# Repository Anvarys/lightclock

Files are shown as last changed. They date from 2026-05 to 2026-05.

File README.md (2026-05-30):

<div align="center">
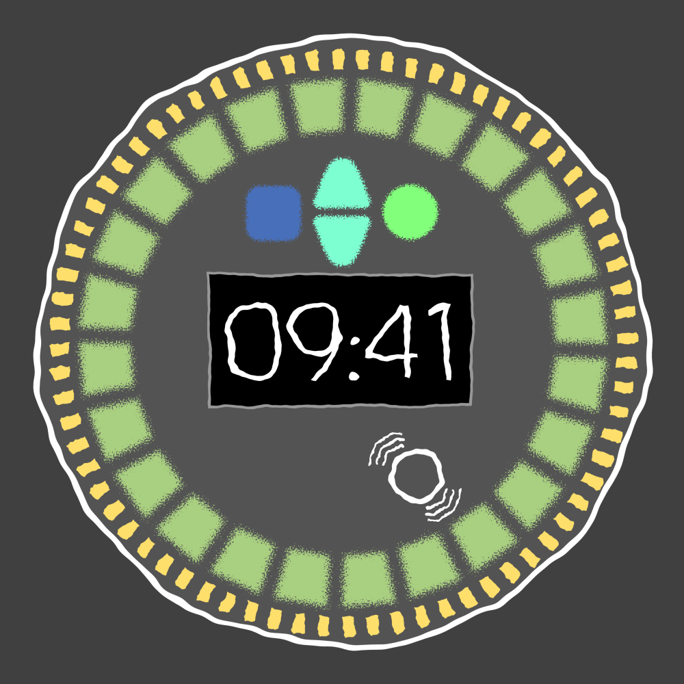
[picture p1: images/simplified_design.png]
Light clock
  
</div>

<h2 align="center">Light Clock</h2>
<p align="center">
A custom PCB-based Clock/Alarm with a runrise alarm, a circle of capacitive touch controls to easily choose the time and a 2.42" OLED display
</p>

## About the project

A custom PCB-based Clock/Alarm with a 3d printed enclosure. It features a runrise alarm option (72 LEDs), a 2.42" OLED display, many capacitive touch controls (24 around in a circle and 4 for the main controls) and a buzzer.

I made this project because I wanted to have a runrise alarm to wake up more naturally and also be easy to set up alarms with few clicks and without any additional installation required.

## Light Clock's features in more detail

### Sunrise alarm & LEDs

Light Clock has a runsrise type of alarm, which will slowly rise the luminosity up to a set time for you to wake up naturally, like with a real sunrise. This can be calibrated, meaning you can set up a test alarm on a day you don't need to wake up at a certain time and see at which luminosity you will wake up. There is also a buzzer (the shaky circle on the simplified design picture) to wake you up with it, just in case, as you might not wake up from the light.

It uses 72LEDs with 3000K warm lighting, with a total maximum luminosity flux of over 2000 lumens. They can also be lighten up in individual groups of 3, so a total of 24 groups is present, to show the current time using those same LEDs but dimmed, also as it has 24 groups it can do both 24 and 12 sections for the time, which you can choose as you prefer.

### Capacitive touch controls

This project has a total of 28 capacitive touch sensors (you can identify all of them on the simplified design picture as the ones having unclear borders), they were made by placing pads on the PCB and using ICs to measure precise capacitance values. 

4 of them are used to control the menu: 2 arrows for navigating between options and change values, a circle to select an option and a square be used as a return button.

And the other 24 are distributed evenly in a circle next to the LEDs, they will be used to easily choose time of your alarm or change number variables. For example if you need to setup an alarm for 10:15am you can simply click the 10th pad counting clockwise from the top to set the hour, and then click on 7th pad to set the minutes.

### Display

The display is a 2.42" OLED display from Waveshare. It has a resolution of 128x64, which is not detailed, but very sufficent for pixeled fonts and interfaces. It will display the time in the format you prefer, and it can be set into a "show on touch" mode, so that the display would be off by default but when you touch any capacitive touch sensor it will show the time for a certain period of time.

### Other

It also has an RTC clock with a coin battery to sustain precise time for months, while the battery is not required it is very recommended as then if you power off the clock you won't need to set up the time again each time.

Since the LEDs and ICs produce heat there is a 40x40x7mm fan on the back which is very quiet, so should not be a worry that it might be disturbing.

Also I added 4 exposed GPIO pads on the PCB that you can use them to integrate something extra to this device if you want to.

## How to build your own light clock

First you would want to buy all the required components found in the [BOM](https://github.com/Anvarys/lightclock/blob/main/BOM/BOM.csv), order the pcb using the gerbers from the [production folder](https://github.com/Anvarys/lightclock/tree/main/PCB/production) (you can also find the positions file which is required for JLCPCB to solder components for you, which is also an option). Then you will need to solder everything by looking at the [schematic](https://github.com/Anvarys/lightclock/blob/main/images/schematic.pdf) for references of the components. Also you will need to 3d print the enclosure, files of which you can find in the [CAD folder](https://github.com/Anvarys/lightclock/tree/main/CAD). Now you will need to flash the device with the [firmware](https://github.com/Anvarys/lightclock/tree/main/firmware) using [VS code](https://code.visualstudio.com) with [PlatformIO](https://platformio.org). Then when you check that it boots up successfully you can assemble the enclosure by first mounting the fan on the back enclosure part, then mounting the pcb to it as well, and finally snap the front enclosure part on the PCB.

## Schematic

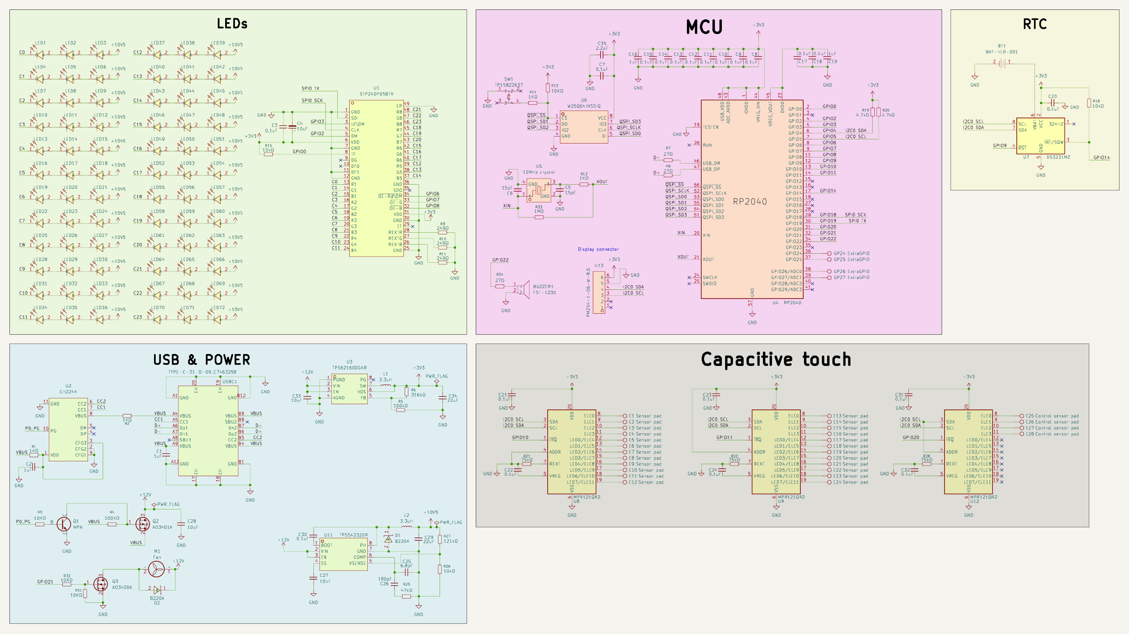
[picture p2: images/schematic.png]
schematic image


## PCB

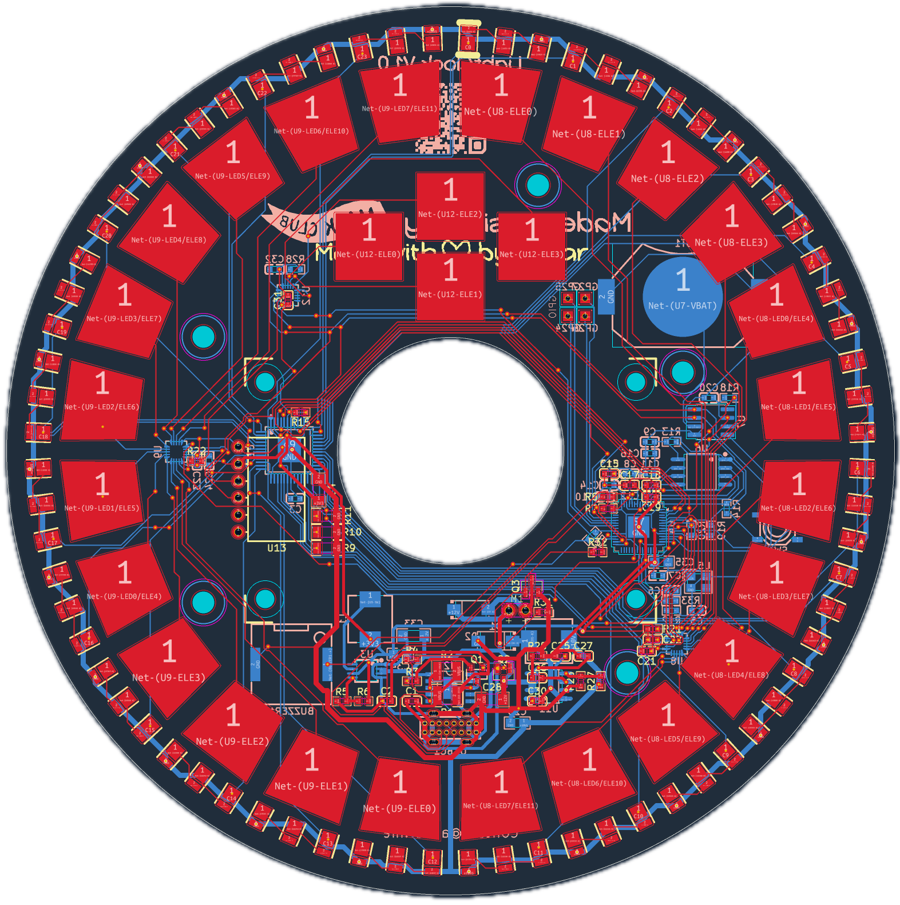
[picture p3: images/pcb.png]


3D renders:

<table><tr>
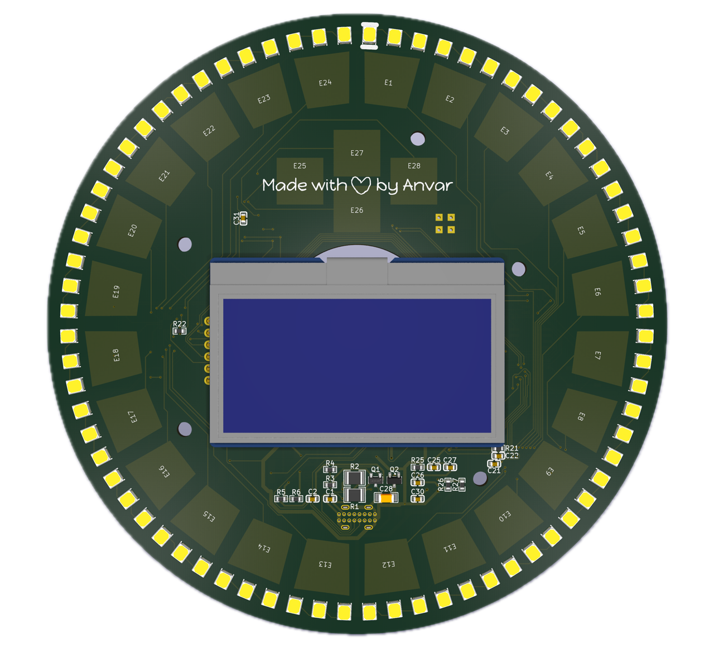
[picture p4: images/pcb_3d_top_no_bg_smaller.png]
<td></td>
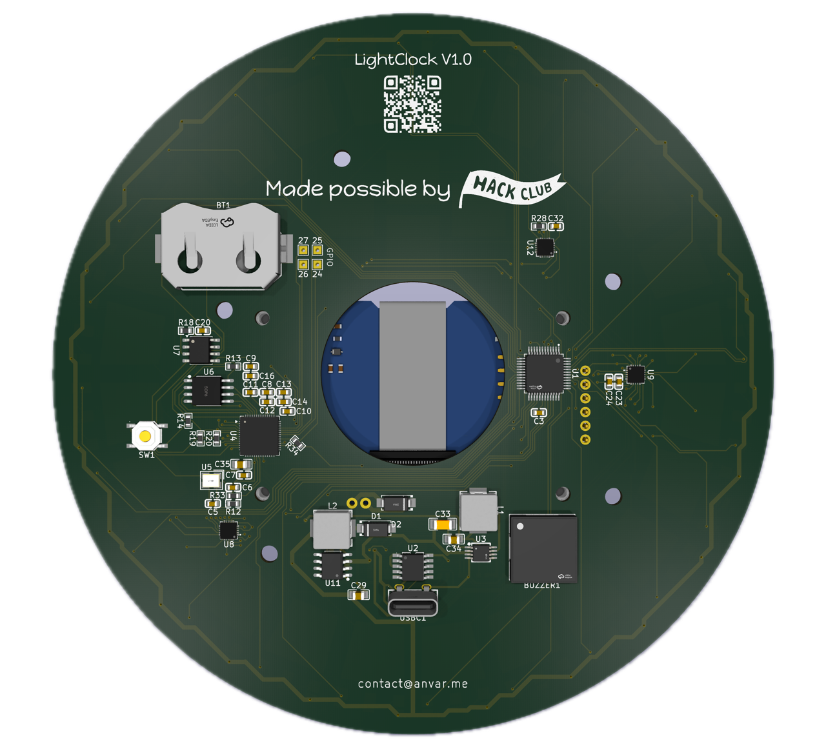
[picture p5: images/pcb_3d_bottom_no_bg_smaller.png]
<td></td>
</tr></table>

## Assembly

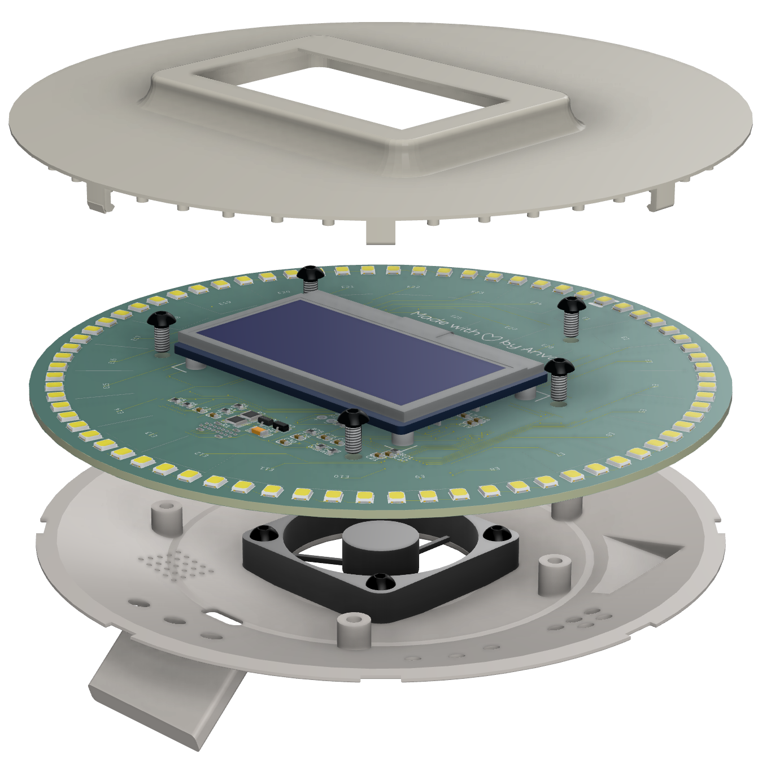
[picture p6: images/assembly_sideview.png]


## Assembled

<table><tr>
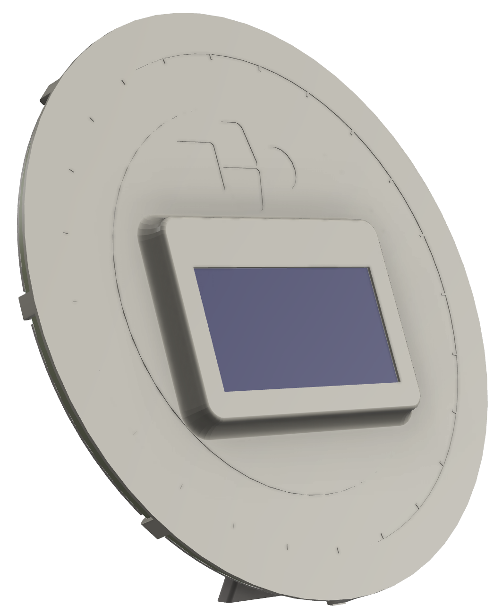
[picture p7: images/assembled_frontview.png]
<td></td>
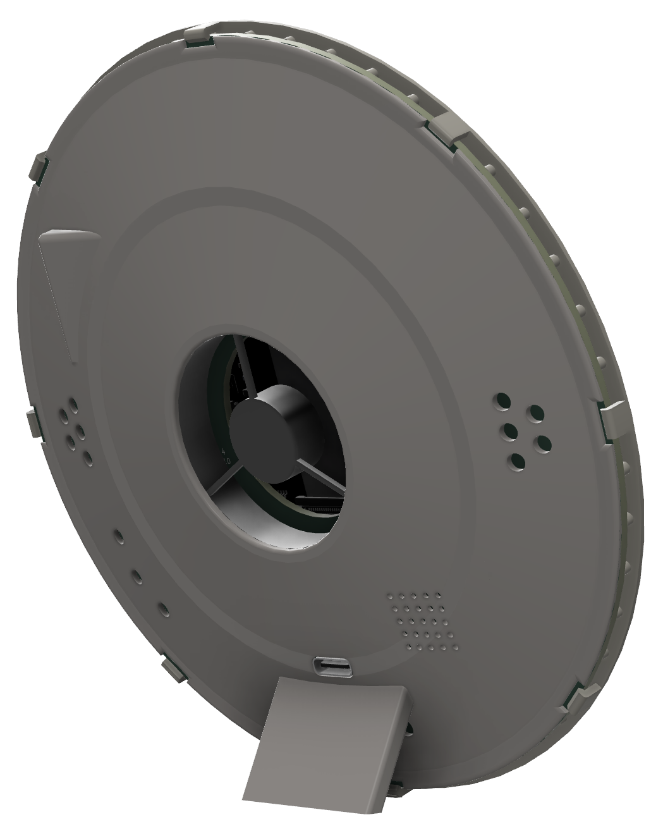
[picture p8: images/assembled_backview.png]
<td></td>
</tr></table>

## Tools I used

<ul style="list-style-type:none;">
  <li>PCB design: <a href="https://kicad.org">KiCAD</a></li>
  <li>3D design: <a href="https://www.autodesk.com/products/fusion-360/overview">Autodesk Fusion</a> (free version)</li>
  <li>Firmware: <a href="https://code.visualstudio.com">VS code</a> with <a href="https://platformio.org">PlatformIO</a></li>
  <li>Art: <a href="https://figma.com">Figma</a></li>
</ul>

## BOM

Totals
| | |
|-|-|
|Parts|102.84$|
|Supplies|22.08$|
|Shipping|39.34$|
|Everything|164.26$|

You can find the detailed BOM in [/BOM](https://github.com/Anvarys/lightclock/tree/main/BOM)

P.S. I had to choose fast shipping or amazon instead of aliexpress as otherwise I won't be able to build the project until August

## Repository structure

- [/CAD](https://github.com/Anvarys/lightclock/tree/main/CAD) - All the 3d models and the assembly
- [/PCB](https://github.com/Anvarys/lightclock/tree/main/PCB) - KiCAD PCB project
  - [/production](https://github.com/Anvarys/lightclock/tree/main/PCB/production) - Files required to produce the PCB (and PCBA for JLCPCB)
  - [/scripts](https://github.com/Anvarys/lightclock/tree/main/PCB/scripts) - Scripts I made in python to place the LEDs and capacitive touch pad footprints perfectly on the PCB
- [/firmware](https://github.com/Anvarys/lightclock/tree/main/firmware) - PlatformIO project with all firmware sources and configs
- [/BOM](https://github.com/Anvarys/lightclock/tree/main/BOM) - Bill of materials (the list of all parts you need to buy)
- [/images](https://github.com/Anvarys/lightclock/tree/main/images) - Images of the project such as 3d renders, schematic, PCB, zine, etc.

## Zine

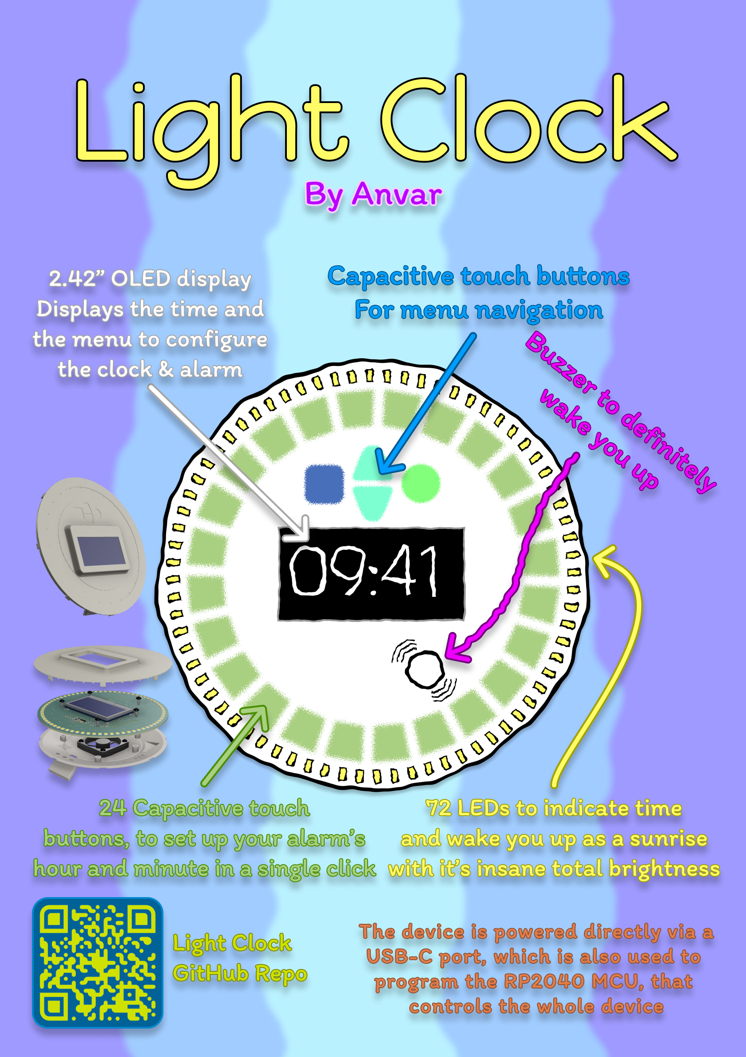
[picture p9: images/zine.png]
zine


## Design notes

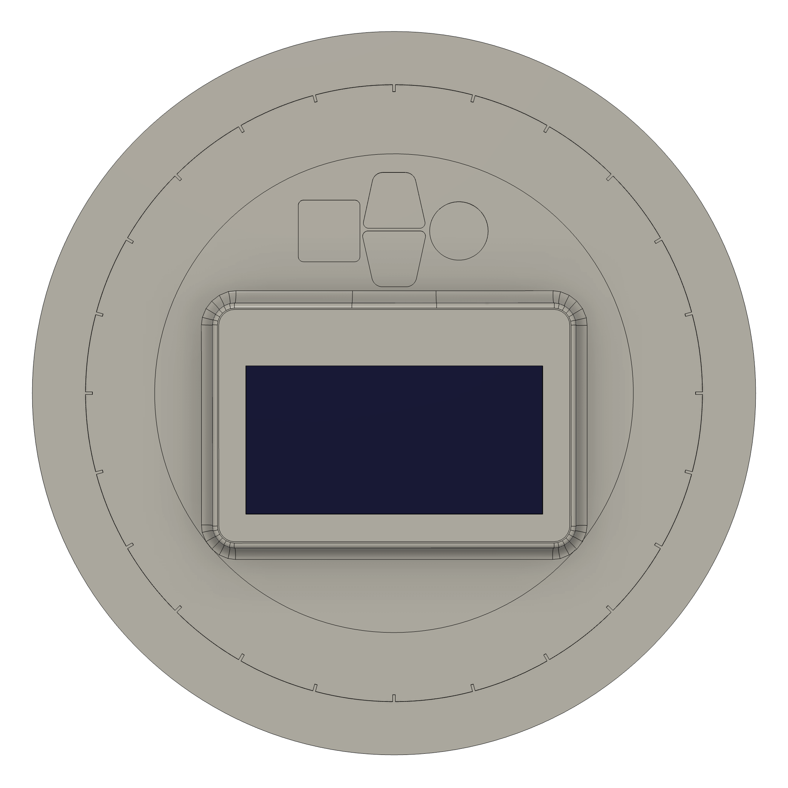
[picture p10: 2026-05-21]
images/front.png

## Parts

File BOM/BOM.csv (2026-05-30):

Name | Qty needed | Qty bought | Link | Price (Qty bought) | Running total | Note
LED driver | 1 | 1 | https://www.lcsc.com/product-detail/C157417.html | US$3.29 | US$3.29
LED | 72 | 80 | https://www.lcsc.com/product-detail/C17215415.html | US$0.94 | US$4.23
RP2040 MCU | 1 | 1 | https://www.lcsc.com/product-detail/C2040.html | US$0.95 | US$5.18
USB-C PD controller | 1 | 1 | https://www.lcsc.com/product-detail/C970725.html | US$0.61 | US$5.79
USB-C port | 1 | 5 | https://www.lcsc.com/product-detail/C7463258.html | US$1.20 | US$6.99
Step-down buck converter to 3.3V | 1 | 1 | https://www.lcsc.com/product-detail/C60726.html | US$1.32 | US$8.31
12MHz crystal | 1 | 5 | https://www.lcsc.com/product-detail/C2901650.html | US$0.38 | US$8.69
32Mbit flash | 1 | 1 | https://www.lcsc.com/product-detail/C179173.html | US$1.66 | US$10.35 | can be interchanged with any memory size of the same family (up to 128Mbit)
RTC IC | 1 | 1 | https://www.lcsc.com/product-detail/C107410.html | US$3.01 | US$13.36
Coin battery holder | 1 | 1 | https://www.lcsc.com/product-detail/C7501066.html | US$0.82 | US$14.18
6P Socket for the display | 1 | 6 | https://www.lcsc.com/product-detail/C2897388.html | US$0.99 | US$15.17
Step-down buck converter to 10.5V | 1 | 5 | https://www.lcsc.com/product-detail/C52653.html | US$2.03 | US$17.20
Capacitive touch IC | 3 | 3 | https://www.lcsc.com/product-detail/C91322.html | US$9.56 | US$26.76
Buzzer | 1 | 1 | https://www.lcsc.com/product-detail/C255333.html | US$1.17 | US$27.93
NPN transitor | 1 | 5 | https://www.lcsc.com/product-detail/C7603172.html | US$0.04 | US$27.97
AO3401A | 1 | 10 | https://www.lcsc.com/product-detail/C15127.html | US$0.59 | US$28.56
AO3400A | 1 | 5 | https://www.lcsc.com/product-detail/C20917.html | US$0.41 | US$28.97
3.3uH inductor | 2 | 5 | https://www.lcsc.com/product-detail/C167219.html | US$0.85 | US$29.82
B220A diode | 2 | 5 | https://www.lcsc.com/product-detail/C110481.html | US$0.47 | US$30.29
Tactile button | 1 | 10 | https://www.lcsc.com/product-detail/C49140441.html | US$0.42 | US$30.71
6.8pF capacitor | 1 | 50 | https://www.lcsc.com/product-detail/C318672.html | US$0.53 | US$31.24
15pF capacitor | 2 | 100 | https://www.lcsc.com/product-detail/C1644.html | US$0.60 | US$31.84
180pF capacitor | 1 | 100 | https://www.lcsc.com/product-detail/C107041.html | US$0.43 | US$32.27
10nF capacitor | 1 | 50 | https://www.lcsc.com/product-detail/C1589.html | US$0.20 | US$32.47
0.1uF capacitor | 20 | 50 | https://www.lcsc.com/product-detail/C15725.html | US$0.35 | US$32.82
1uF capacitor | 4 | 50 | https://www.lcsc.com/product-detail/C5199872.html | US$0.45 | US$33.27
2.2uF capacitor | 1 | 10 | https://www.lcsc.com/product-detail/C19110.html | US$0.19 | US$33.46
10uF capacitor | 3 | 10 | https://www.lcsc.com/product-detail/C9807.html | US$0.39 | US$33.85
22uF capacitor | 2 | 10 | https://www.lcsc.com/product-detail/C602037.html | US$0.43 | US$34.28
27Ω resistor | 3 | 100 | https://www.lcsc.com/product-detail/C25190.html | US$0.15 | US$34.43
249Ω ±0.1% resistor | 3 | 10 | https://www.lcsc.com/product-detail/C870575.html | US$0.73 | US$35.16 | ±0.1% because it controls LED driver's max output intensity
1kΩ resistor | 2 | 100 | https://www.lcsc.com/product-detail/C2907113.html | US$0.11 | US$35.27
1kΩ 500mW resistor | 2 | 2 | https://www.lcsc.com/product-detail/C966306.html | US$0.01 | US$35.28 | R1, R2: usb-c PD, required ≥400mW
10kΩ resistor | 6 | 20 | https://www.lcsc.com/product-detail/C95204.html | US$0.44 | US$35.72 | ±0.1% resistor, not required but recommended for R26, controls the 10.5V Vout of a converter
4.7kΩ resistor | 2 | 100 | https://www.lcsc.com/product-detail/C2907034.html | US$0.12 | US$35.84
100kΩ ±0.1% resistor | 2 | 20 | https://www.lcsc.com/product-detail/C122538.html | US$0.45 | US$36.29 | ±0.1% because it controls 3.3V Vout of a converter (R5)
1MΩ resistor | 1 | 100 | https://www.lcsc.com/product-detail/C2907115.html | US$0.11 | US$36.40
75kΩ resistor | 3 | 100 | https://www.lcsc.com/product-detail/C114636.html | US$0.16 | US$36.56
47kΩ resistor | 1 | 100 | https://www.lcsc.com/product-detail/C105579.html | US$0.16 | US$36.72
316kΩ ±0.1% resistor | 1 | 20 | https://www.lcsc.com/product-detail/C861833.html | US$0.55 | US$37.27 | ±0.1% because it controls 3.3V Vout of a converter (R6)
121kΩ resistor | 1 | 20 | https://www.lcsc.com/product-detail/C861095.html | US$0.52 | US$37.79 | ±0.1% resistor, not required but recommended for R27, controls the 10.5V Vout of a converter
LCSC FedEx fast shipping |  |  | - | US$29.40 | US$67.19 | Without fast shipping I won't be able to build it in time
LCSC shipping coupon |  |  |  | -US$5.00 | US$62.19
JLCPCB PCB + stencil | 1 | 5 | https://jlcpcb.com | US$18.21 | US$80.40
JLCPCB DHL fast shipping |  |  | - | US$24.94 | US$105.34
JLCPCB customs |  |  |  | US$6.63 | US$111.97
JLCPCB shipping coupon |  |  |  | -US$10.00 | US$101.97 | New user shipping coupon
M2.5 5mm screws | 9 | 50 | https://www.amazon.fr/Inovey-Stainless-Hexagon-Ultrathin-Socket/dp/B0D59JTN94 | US$5.85 | US$107.82 | flat head, must have: dk <= 6.5mm && k <= 1.4mm | there are cheaper options on aliexpress, but if you need it to ship fast, amazon is the cheapest option
M3 6mm screws | 5 | 50 | https://www.amazon.fr/Inovey-Stainless-Hexagon-Ultrathin-Socket/dp/B0D59JTN94 | US$5.85 | US$113.67 | flat head, must have: dk <= 6.5mm && k <= 1.4mm | there are cheaper options on aliexpress, but if you need it to ship fast, amazon is the cheapest option
Waveshare 2.42" display | 1 | 1 | https://www.amazon.fr/Waveshare-Resolution-Communication-Compatible-Raspberry/dp/B0CL6WMHJN | US$25.64 | US$139.31 | there are cheaper options on aliexpress, but if you need it to ship fast, amazon is the cheapest option
Fan 12V | 1 | 1 | https://fr.aliexpress.com/item/1005002566049059.html | US$2.87 | US$142.18
3D printing Filament | 80g | 1kg | https://www.amazon.fr/ELEGOO-Imprimante-Précision-Dimensionnelle-Imprimantes/dp/B0D4Z8QT5T | US$22.08 | US$164.26 | preferably matte
Total |  |  |  | US$164.26

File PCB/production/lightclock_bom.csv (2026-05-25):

Designator | Footprint | Quantity | Value | LCSC Part #
BT1 | BAT-SMD_BAT-HLD-001 | 1 | BAT-HLD-001 | C7501066
BUZZER1 | BUZ-SMD_L12.0-W12.0_FUET-1230 | 1 | FST-1230 | C391037
C1, C16, C19, C2 | C0603 | 4 | 1uF | C1644
C10, C11, C12, C13, C14, C15, C17, C18, C20, C21, C22, C23, C24, C3, C30, C31, C32, C7, C8, C9 | C0603 | 20 | 0.1uF | C1644
C25 | C0603 | 1 | 6.8pF | C1644
C26 | C0603 | 1 | 180pF | C1644
C27 | C0603 | 1 | 10nF | C1644
C28, C33, C4 | C1206 | 3 | 10uF | C9807
C29, C34 | C0805 | 2 | 22uF | C602037
C35 | C0805 | 1 | 2.2uF | C602037
C5, C6 | C0603 | 2 | 15pF | C1644
D1, D2 | SMA_L4.4-W2.8-LS5.4-RD | 2 | B220A | C110481
E1, E10, E11, E12, E13, E14, E15, E16, E17, E18, E19, E2, E20, E21, E22, E23, E24, E3, E4, E5, E6, E7, E8, E9 | capacitive-touch-pad-trapezoid | 24 | Sensor pad
E25, E26, E27, E28 | capacitive-touch-pad-square10mm | 4 | Control sensor pad
GP24, GP25, GP26, GP27 | TestPoint_THTPad_1.5x1.5mm_Drill0.7mm | 4 | ExtraGPIO
L1, L2 | IND-SMD_L7.0-W6.6 | 2 | 3.3uH | C167219
LED1, LED10, LED11, LED12, LED13, LED14, LED15, LED16, LED17, LED18, LED19, LED2, LED20, LED21, LED22, LED23, LED24, LED25, LED26, LED27, LED28, LED29, LED3, LED30, LED31, LED32, LED33, LED34, LED35, LED36, LED37, LED38, LED39, LED4, LED40, LED41, LED42, LED43, LED44, LED45, LED46, LED47, LED48, LED49, LED5, LED50, LED51, LED52, LED53, LED54, LED55, LED56, LED57, LED58, LED59, LED6, LED60, LED61, LED62, LED63, LED64, LED65, LED66, LED67, LED68, LED69, LED7, LED70, LED71, LED72, LED8, LED9 | LED-SMD_L3.5-W2.8-RD_GW-JTLRS1.EM-K5L4-XX57-1 | 72 | GW JTLMS1.EM-GVH3-XX57-1-60-R33 | C17215415
M1 | SMD_2pads_polar_4mm_square | 1 | Fan
Q1 | SOT-23-3_L2.9-W1.3-P1.90-LS2.4-BR | 1 | NPN | C347475
Q2 | SOT-23 | 1 | AO3401A
Q3 | SOT-23 | 1 | AO3400A
R1, R2 | R1210 | 2 | 1KΩ | C966306
R10, R11, R9 | R1206 | 3 | 249Ω | C870575
R12, R14 | R0603 | 2 | 1KΩ | C25190
R13, R15, R18, R26, R3, R31, R32 | R0603 | 7 | 10KΩ | C25190
R19, R20 | R0603 | 2 | 4.7kΩ | C25190
R21, R22, R28 | R0603 | 3 | 75kΩ | C25190
R25 | R0603 | 1 | 47kΩ | C25190
R27 | R0603 | 1 | 121kΩ | C25190
R33 | R0603 | 1 | 1MΩ | C25190
R34, R7, R8 | R0603 | 3 | 27Ω | C25190
R4, R5 | R0603 | 2 | 100KΩ | C25190
R6 | R0603 | 1 | 316kΩ | C25190
SW1 | SW-SMD_4P-L5.2-W5.2-P3.70-LS6.4 | 1 | TP15822637 | C49140441
U1 | TQFP-48_L7.0-W7.0-P0.50-LS9.0-BL-EP3.5 | 1 | STP24DP05BTR | C157417
U11 | SOIC-8_L4.9-W3.9-P1.27-LS6.0-BL | 1 | TPS54232DR | C52653
U12, U8, U9 | QFN-20_L3.0-W3.0-P0.40-BL | 3 | MPR121QR2 | C91322
U13 | HDR-TH_6P-P2.54-H-F-W10.0-N | 1 | PM254-1-06-W-8.5 | C2897388
U2 | ESSOP-10_L4.9-W3.9-P1.0-LS6.0-TL-EP | 1 | CH224K | C970725
U3 | MSOP-8_L3.0-W3.0-P0.65-LS5.0-BL | 1 | TPS62160DGKR | C60726
U4 | QFN-56-1EP_7x7mm_P0.4mm_EP3.2x3.2mm | 1 | RP2040
U5 | CRYSTAL-SMD_4P-L3.2-W2.5-BL | 1 | 12MHz crystal | C2901650
U6 | SOP-8_L5.3-W5.3-P1.27-LS8.0-BL | 1 | W25Q64JVSSIQ | C83140
U7 | SOIC-8_3.9x4.9mm_P1.27mm | 1 | DS3231MZ
USBC1 | USB-C-TH_TYPE-C-31-D-09 | 1 | TYPE-C-31-D-09_C7463258 | C7463258

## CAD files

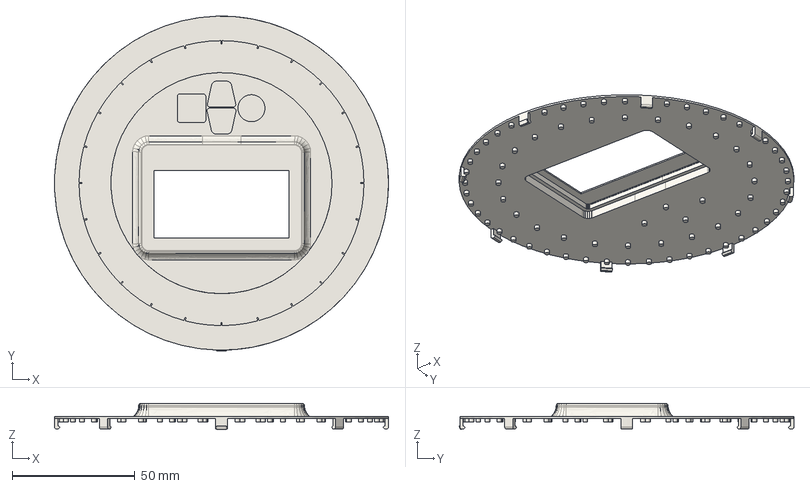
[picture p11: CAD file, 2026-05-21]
CAD/enclosure-front.step
136.0 x 136.3 x 10.8 mm

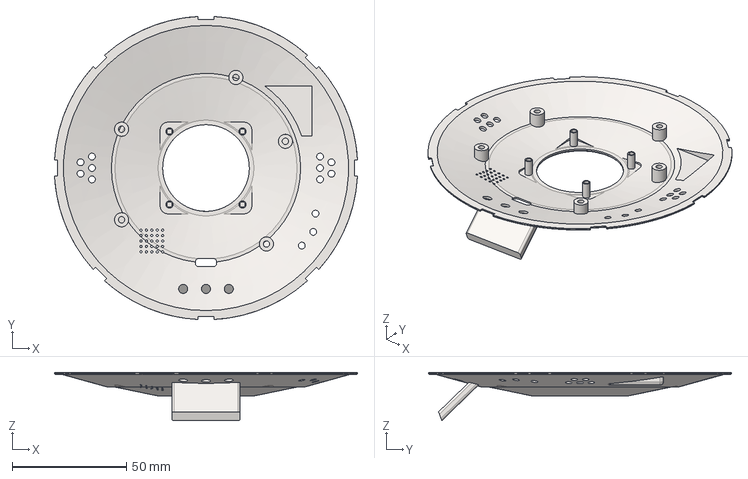
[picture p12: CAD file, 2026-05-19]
CAD/enclosure-back.step
132.8 x 132.8 x 21.2 mm

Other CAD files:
CAD/enclosure-back-fusion.f3d
CAD/enclosure-back.stl
CAD/enclosure-front-fusion.f3d
CAD/enclosure-front.stl

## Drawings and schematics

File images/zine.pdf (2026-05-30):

## Light Clock By Anvar

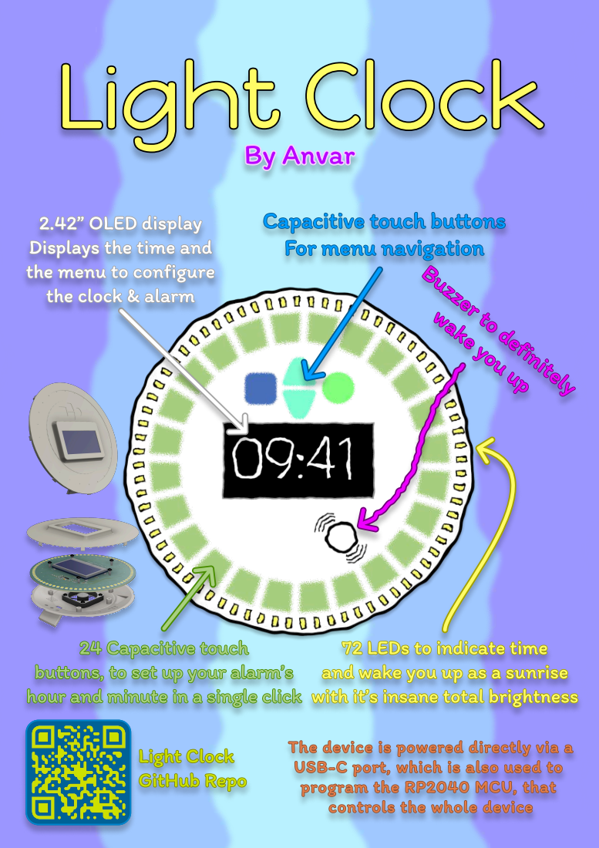
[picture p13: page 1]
2.42” OLED display; 24 Capacitive touch; Light Clock; GitHub Repo

Capacitive touch buttons

Displays the time and

For menu navigation

the menu to configure

Buzzer to definitely

the clock & alarm

wake you up

72 LEDs to indicate time

buttons, to set up your alarm’s

and wake you up as a sunrise

hour and minute in a single click

with it’s insane total brightness

The device is powered directly via a

USB-C port, which is also used to
program the RP2040 MCU, that

controls the whole device

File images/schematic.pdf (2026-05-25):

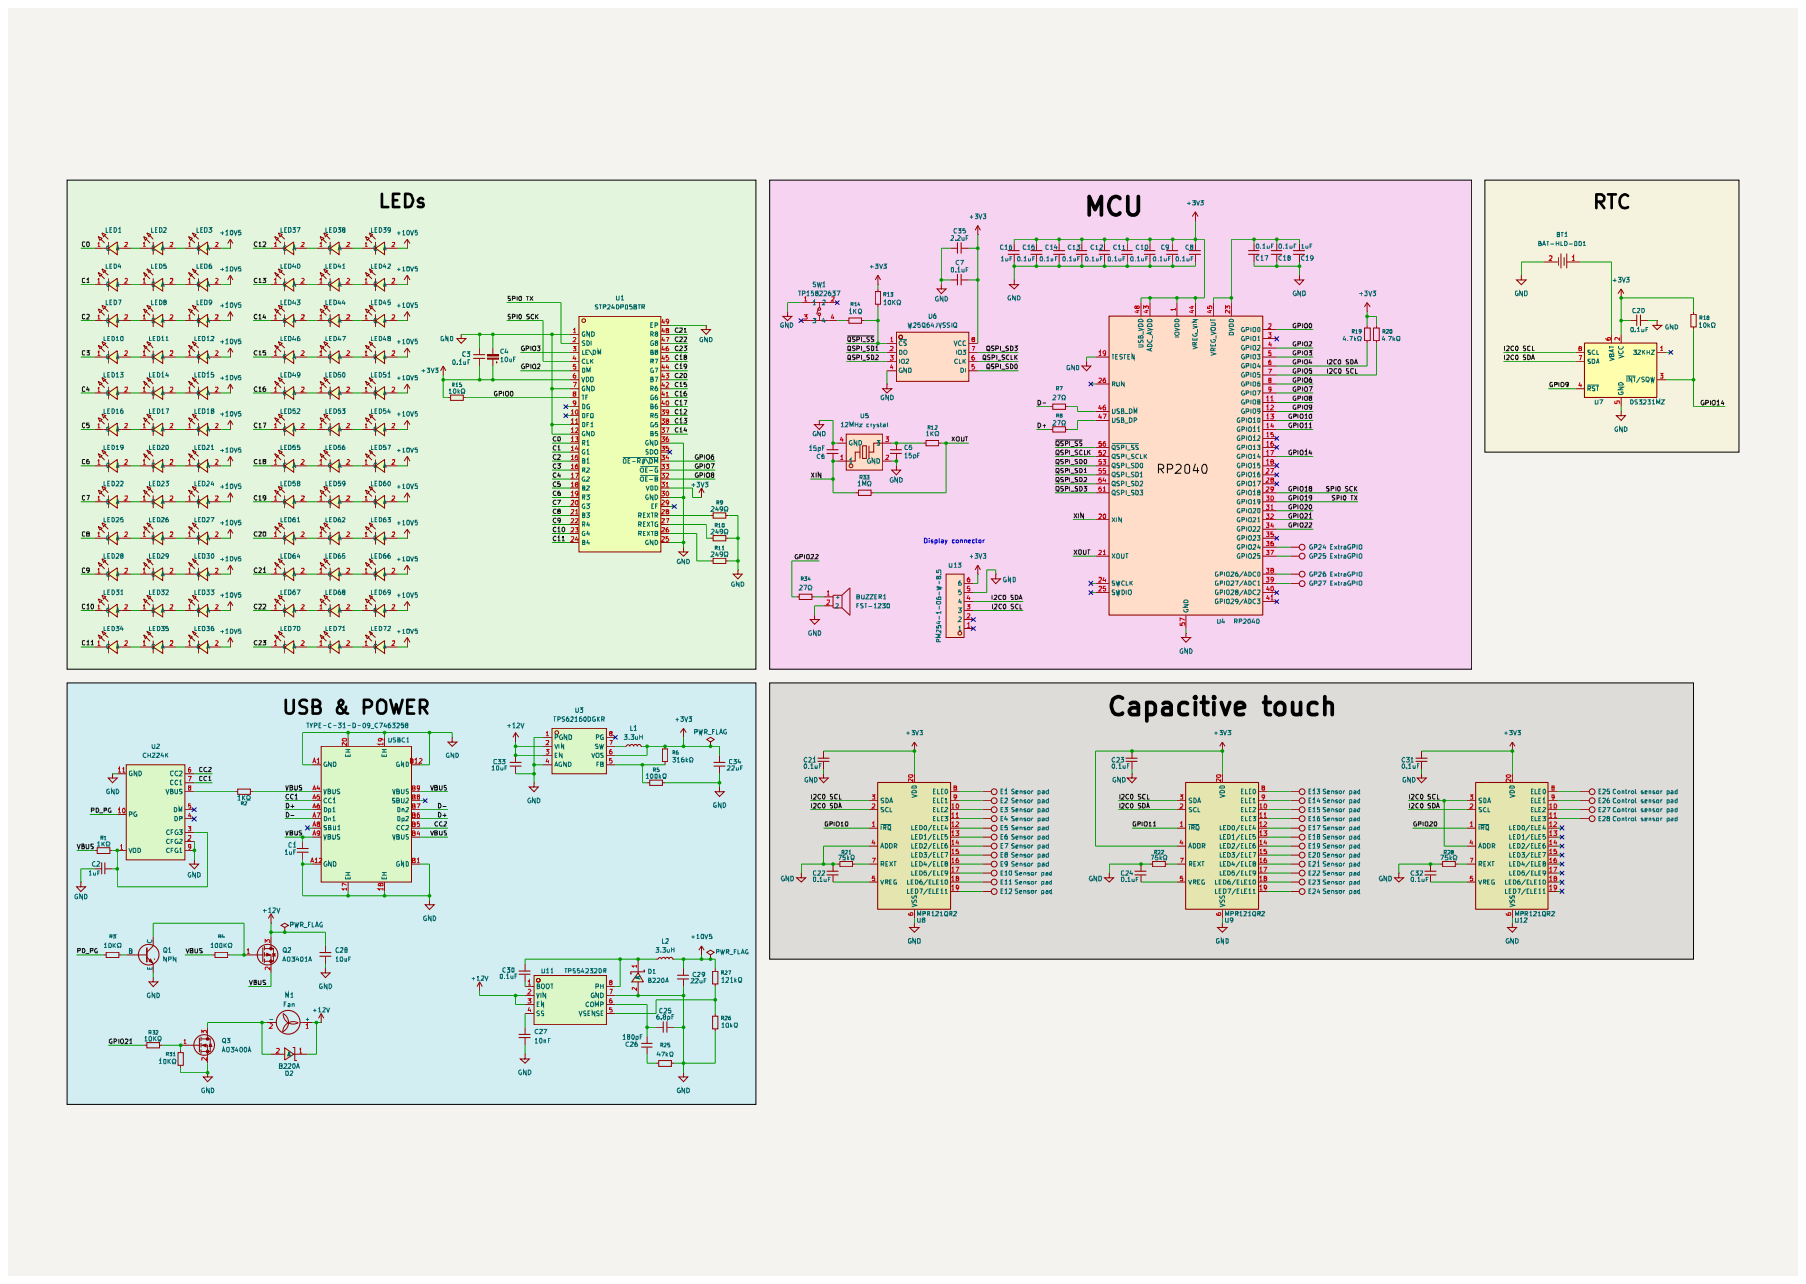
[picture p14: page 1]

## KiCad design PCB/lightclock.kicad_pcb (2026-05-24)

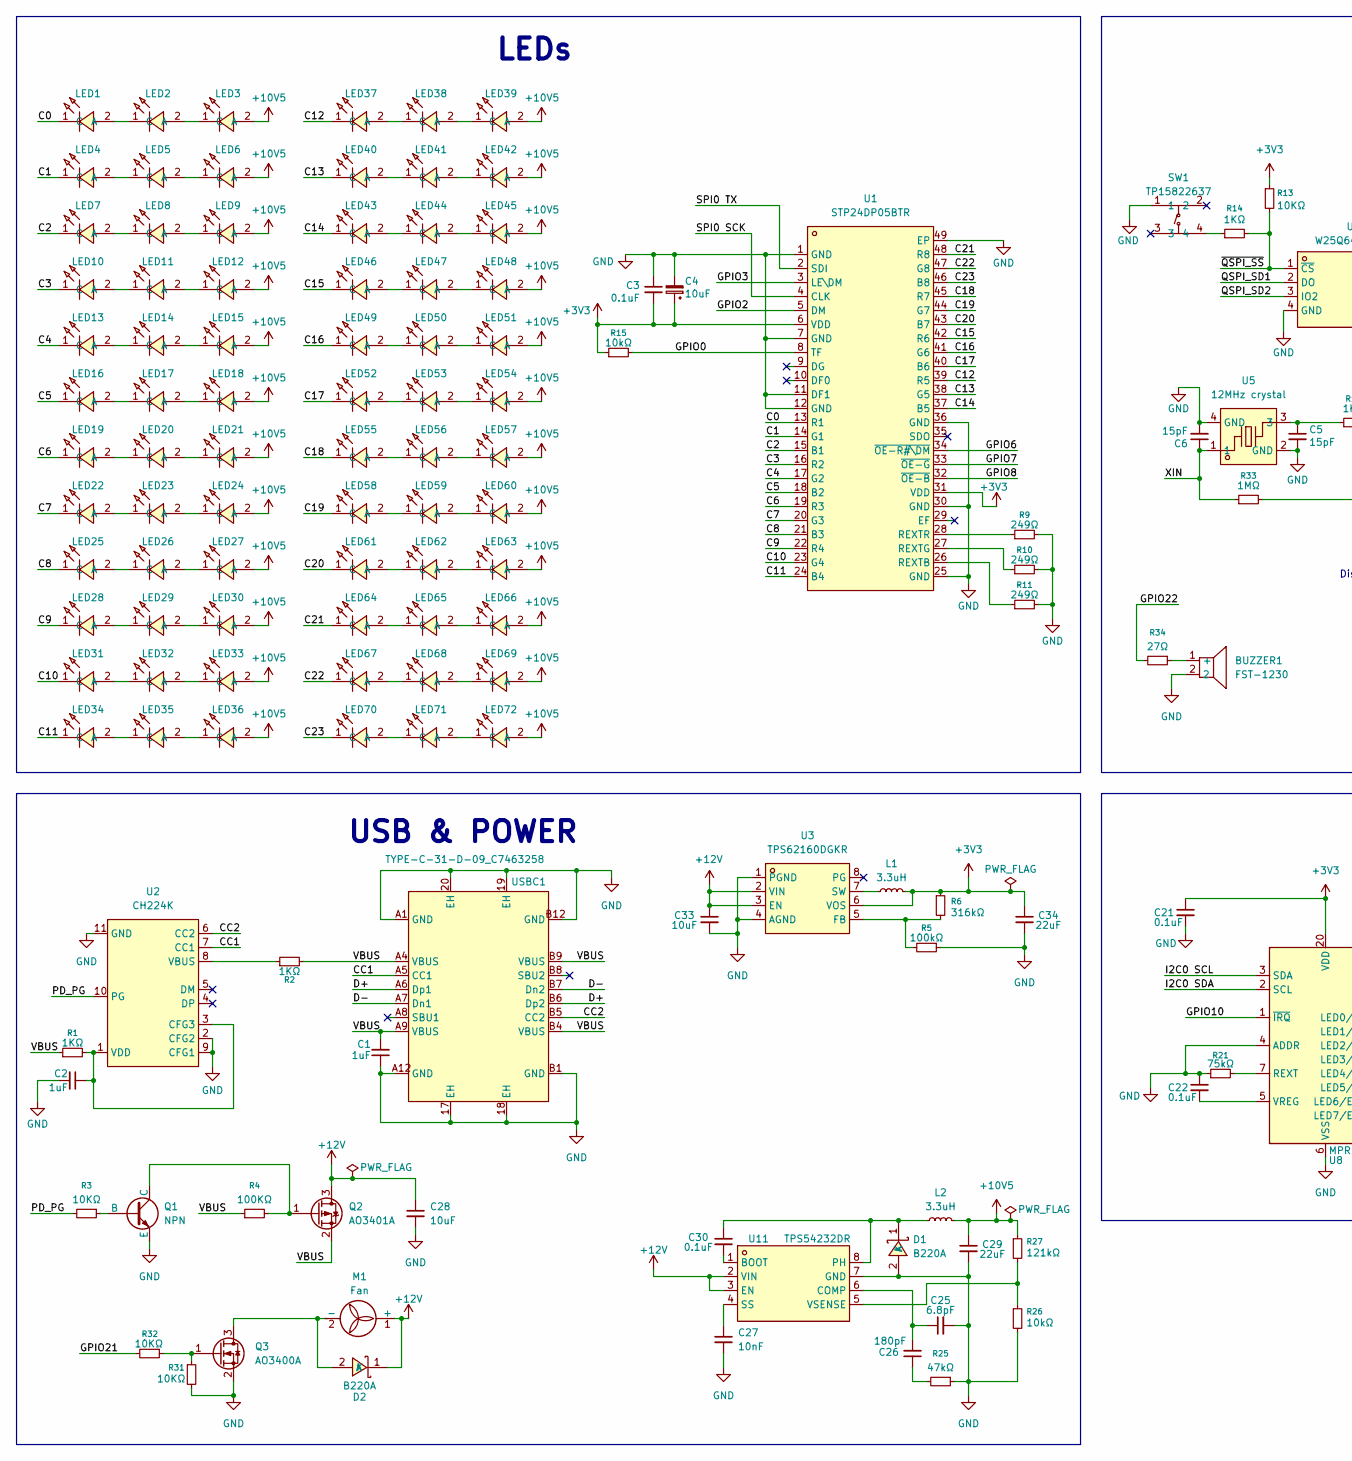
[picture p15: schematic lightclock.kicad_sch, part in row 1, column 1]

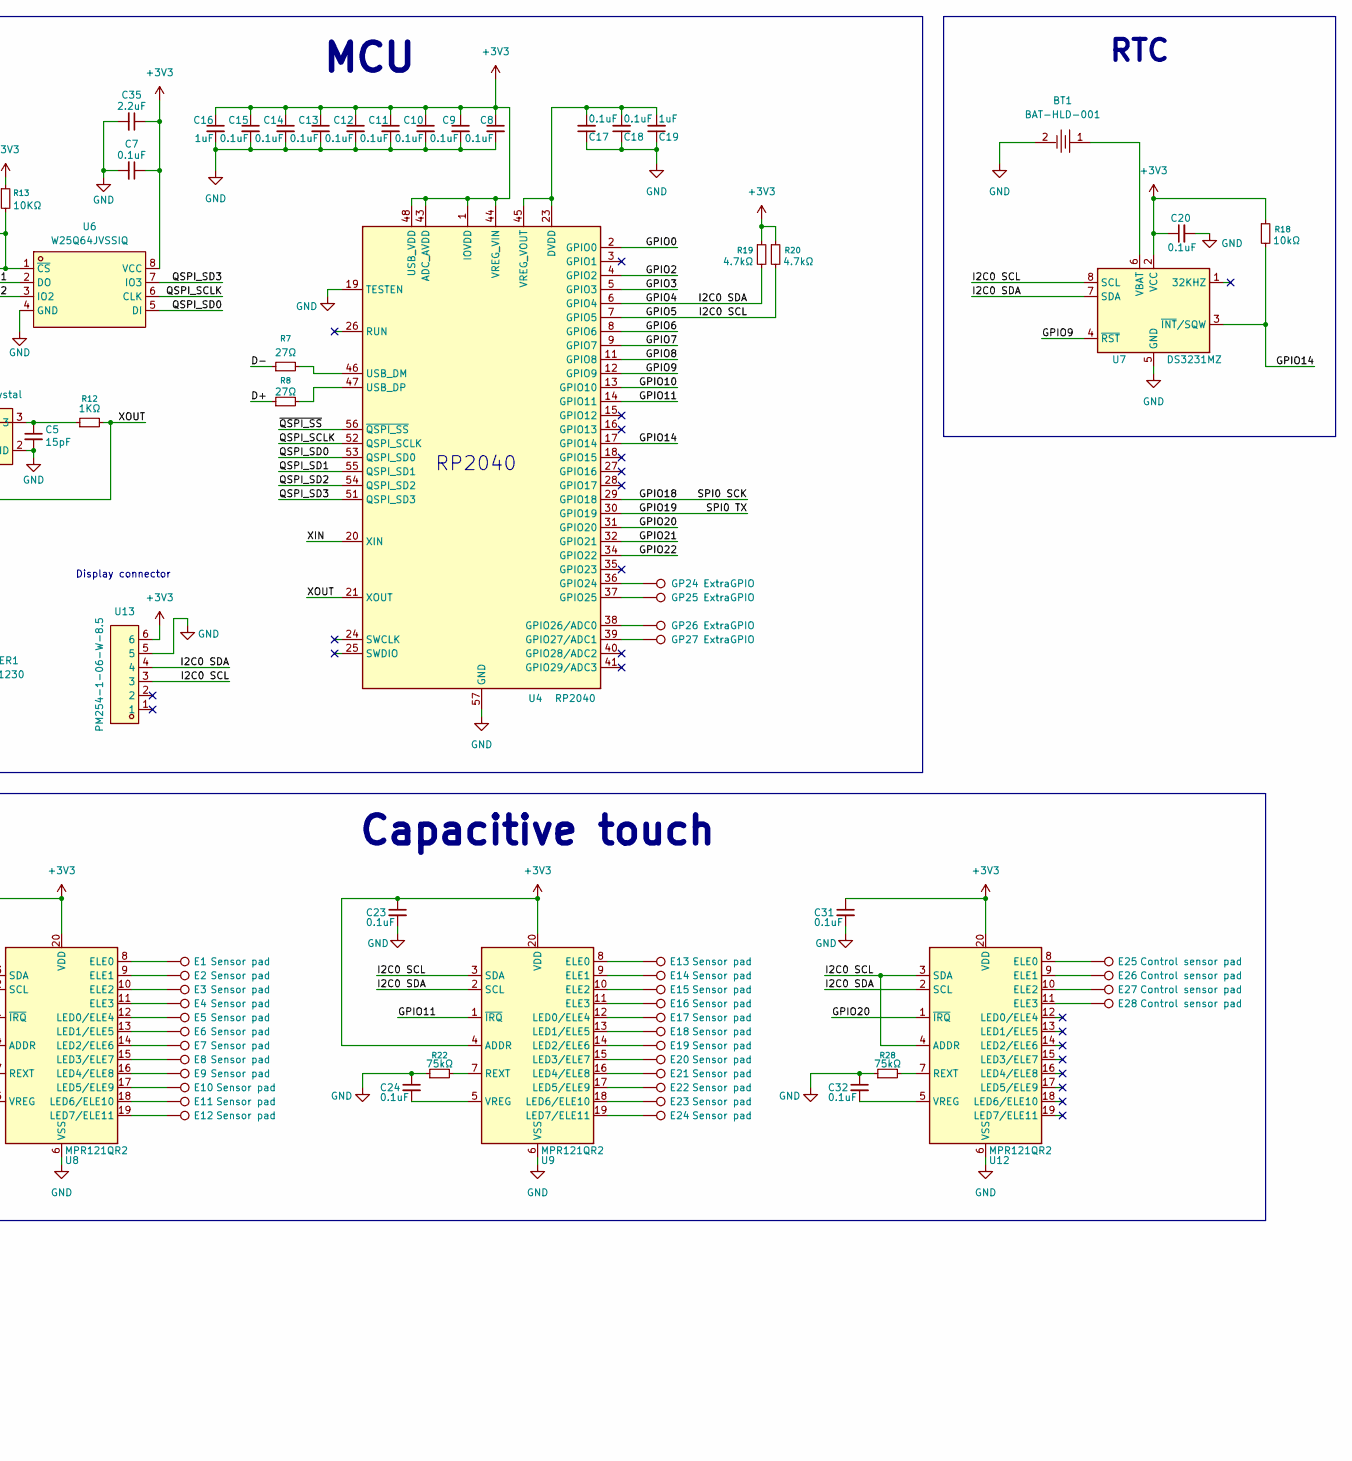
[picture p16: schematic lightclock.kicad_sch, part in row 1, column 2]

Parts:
BT1: BAT-HLD-001; BAT-SMD_BAT-HLD-001; MPN BAT-HLD-001; LCSC Part C7501066
BUZZER1: FST-1230; BUZ-SMD_L12.0-W12.0_FUET-1230; MPN FUET-1230; LCSC Part C391037
C1, C2, C16, C19: 1uF; C0603
C3, C7, C8, C9, C10, C11, C12, C13, C14, C15, C17, C18, C20, C21, C22, C23, C24, C30, C31, C32: 0.1uF; C0603
C4, C28, C33: 10uF; C1206
C5, C6: 15pF; C0603
C25: 6.8pF; C0603
C26: 180pF; C0603
C27: 10nF; C0603
C29, C34: 22uF; C0805
C35: 2.2uF; C0805
D1, D2: B220A; SMA_L4.4-W2.8-LS5.4-RD; MPN B220A-13-F; LCSC Part C110481
E1, E2, E3, E4, E5, E6, E7, E8, E9, E10, E11, E12, E13, E14, E15, E16, E17, E18, E19, E20, E21, E22, E23, E24: Sensor pad; capacitive-touch-pad-trapezoid
E25, E26, E27, E28: Control sensor pad; capacitive-touch-pad-square10mm
GP24, GP25, GP26, GP27: ExtraGPIO; TestPoint_THTPad_1.5x1.5mm_Drill0.7mm
L1, L2: 3.3uH; IND-SMD_L7.0-W6.6
LED1, LED2, LED3, LED4, LED5, LED6, LED7, LED8, LED9, LED10, LED11, LED12, LED13, LED14, LED15, LED16, LED17, LED18, LED19, LED20, LED21, LED22, LED23, LED24, LED25, LED26, LED27, LED28, LED29, LED30, LED31, LED32, LED33, LED34, LED35, LED36, LED37, LED38, LED39, LED40, LED41, LED42, LED43, LED44, LED45, LED46, LED47, LED48, LED49, LED50, LED51, LED52, LED53, LED54, LED55, LED56, LED57, LED58, LED59, LED60, LED61, LED62, LED63, LED64, LED65, LED66, LED67, LED68, LED69, LED70, LED71, LED72: GW JTLMS1.EM-GVH3-XX57-1-60-R33; LED-SMD_L3.5-W2.8-RD_GW-JTLRS1.EM-K5L4-XX57-1; MPN GW JTLMS1.EM-GVH3-XX57-1-60-R33; LCSC Part C17215415
M1: Fan; SMD_2pads_polar_4mm_square
Q1: NPN; SOT-23-3_L2.9-W1.3-P1.90-LS2.4-BR
Q2: AO3401A; SOT-23
Q3: AO3400A; SOT-23
R1, R2: 1KΩ; R1210
R3, R13, R31, R32: 10KΩ; R0603
R4: 100KΩ; R0603
R5: 100kΩ; R0603
R6: 316kΩ; R0603
R7, R8, R34: 27Ω; R0603
R9, R10, R11: 249Ω; R1206
R12, R14: 1KΩ; R0603
R15, R18, R26: 10kΩ; R0603
R19, R20: 4.7kΩ; R0603
R21, R22, R28: 75kΩ; R0603
R25: 47kΩ; R0603
R27: 121kΩ; R0603
R33: 1MΩ; R0603
SW1: TP15822637; SW-SMD_4P-L5.2-W5.2-P3.70-LS6.4; MPN TP15822637; LCSC Part C49140441
U1: STP24DP05BTR; TQFP-48_L7.0-W7.0-P0.50-LS9.0-BL-EP3.5; MPN STP24DP05BTR; LCSC Part C157417
U2: CH224K; ESSOP-10_L4.9-W3.9-P1.0-LS6.0-TL-EP; MPN CH224K; LCSC Part C970725
U3: TPS62160DGKR; MSOP-8_L3.0-W3.0-P0.65-LS5.0-BL; MPN TPS62160DGKR; LCSC Part C60726
U4: RP2040; QFN-56-1EP_7x7mm_P0.4mm_EP3.2x3.2mm
U5: 12MHz crystal; CRYSTAL-SMD_4P-L3.2-W2.5-BL; MPN SX3B12.000F1210F30; LCSC Part C2901650
U6: W25Q64JVSSIQ; SOP-8_L5.3-W5.3-P1.27-LS8.0-BL; MPN W25Q64JVSSIQ; LCSC Part C83140
U7: DS3231MZ; SOIC-8_3.9x4.9mm_P1.27mm
U8, U9, U12: MPR121QR2; QFN-20_L3.0-W3.0-P0.40-BL
U11: TPS54232DR; SOIC-8_L4.9-W3.9-P1.27-LS6.0-BL; MPN TPS54232DR; LCSC Part C52653
U13: PM254-1-06-W-8.5; HDR-TH_6P-P2.54-H-F-W10.0-N; MPN PM254-1-06-W-8.5; LCSC Part C2897388
USBC1: TYPE-C-31-D-09_C7463258; USB-C-TH_TYPE-C-31-D-09; MPN TYPE-C-31-D-09; LCSC Part C7463258

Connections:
+3V3: C3.2, C4.1, C7.1, C8.1, C9.1, C10.1, C11.1, C12.1, C13.1, C14.1, C15.1, C16.1, C20.1, C21.1, C23.1, C31.1, C34.1, C35.1, L1.2, R6.1, R13.1, R15.1, R18.1, R19.1, R20.1, U1.6 (VDD), U1.31 (VDD), U3.6 (VOS), U4.1 (IOVDD), U4.10 (IOVDD), U4.22 (IOVDD), U4.33 (IOVDD), U4.42 (IOVDD), U4.43 (ADC_AVDD), U4.44 (VREG_VIN), U4.48 (USB_VDD), U4.49 (IOVDD), U6.8 (VCC), U7.2 (VCC), U8.20 (VDD), U9.4 (ADDR), U9.20 (VDD), U12.20 (VDD), U13.6
+10V5: C29.1, L2.2, LED3.2 (A), LED6.2 (A), LED9.2 (A), LED12.2 (A), LED15.2 (A), LED18.2 (A), LED21.2 (A), LED24.2 (A), LED27.2 (A), LED30.2 (A), LED33.2 (A), LED36.2 (A), LED39.2 (A), LED42.2 (A), LED45.2 (A), LED48.2 (A), LED51.2 (A), LED54.2 (A), LED57.2 (A), LED60.2 (A), LED63.2 (A), LED66.2 (A), LED69.2 (A), LED72.2 (A), R27.1
+12V: C28.1, C33.1, D2.1 (K), M1.1 (+), Q2.3 (D), U3.2 (VIN), U3.3 (EN), U11.2 (VIN), U11.3 (EN)
/C0: LED1.1 (C), U1.13 (R1)
/C1: LED4.1 (C), U1.14 (G1)
/C2: LED7.1 (C), U1.15 (B1)
/C3: LED10.1 (C), U1.16 (R2)
/C4: LED13.1 (C), U1.17 (G2)
/C5: LED16.1 (C), U1.18 (B2)
/C6: LED19.1 (C), U1.19 (R3)
/C7: LED22.1 (C), U1.20 (G3)
/C8: LED25.1 (C), U1.21 (B3)
/C9: LED28.1 (C), U1.22 (R4)
/C10: LED31.1 (C), U1.23 (G4)
/C11: LED34.1 (C), U1.24 (B4)
/C12: LED37.1 (C), U1.39 (R5)
/C13: LED40.1 (C), U1.38 (G5)
/C14: LED43.1 (C), U1.37 (B5)
/C15: LED46.1 (C), U1.42 (R6)
/C16: LED49.1 (C), U1.41 (G6)
/C17: LED52.1 (C), U1.40 (B6)
/C18: LED55.1 (C), U1.45 (R7)
/C19: LED58.1 (C), U1.44 (G7)
/C20: LED61.1 (C), U1.43 (B7)
/C21: LED64.1 (C), U1.48 (R8)
/C22: LED67.1 (C), U1.47 (G8)
/C23: LED70.1 (C), U1.46 (B8)
/CC1: U2.7 (CC1), USBC1.A5 (CC1)
/CC2: U2.6 (CC2), USBC1.B5 (CC2)
/D+: R8.1, USBC1.A6 (Dp1), USBC1.B6 (Dp2)
/D-: R7.1, USBC1.A7 (Dn1), USBC1.B7 (Dn2)
/GPIO0: R15.2, U1.8 (TF), U4.2 (GPIO0)
/GPIO2: U1.5 (DM), U4.4 (GPIO2)
/GPIO3: U1.3 (LE\DM), U4.5 (GPIO3)
/GPIO4: R19.2, U4.6 (GPIO4), U7.7 (SDA), U8.2 (SCL), U9.2 (SCL), U12.2 (SCL), U13.4
/GPIO5: R20.2, U4.7 (GPIO5), U7.8 (SCL), U8.3 (SDA), U9.3 (SDA), U12.3 (SDA), U12.4 (ADDR), U13.3
/GPIO6: U1.34 (~OE-R#\DM), U4.8 (GPIO6)
/GPIO7: U1.33 (~OE-G), U4.9 (GPIO7)
/GPIO8: U1.32 (~OE-B), U4.11 (GPIO8)
/GPIO9: U4.12 (GPIO9), U7.4 (~RST)
/GPIO10: U4.13 (GPIO10), U8.1 (~IRQ)
/GPIO11: U4.14 (GPIO11), U9.1 (~IRQ)
/GPIO14: R18.2, U4.17 (GPIO14), U7.3 (~INT/SQW)
/GPIO18: U1.4 (CLK), U4.29 (GPIO18)
/GPIO19: U1.2 (SDI), U4.30 (GPIO19)
/GPIO20: U4.31 (GPIO20), U12.1 (~IRQ)
/GPIO21: R32.2, U4.32 (GPIO21)
/GPIO22: R34.2, U4.34 (GPIO22)
/PD_PG: R3.2, U2.10 (PG)
/QSPI_SCLK: U4.52 (QSPI_SCLK), U6.6 (CLK)
/QSPI_SD0: U4.53 (QSPI_SD0), U6.5 (DI)
/QSPI_SD1: U4.55 (QSPI_SD1), U6.2 (DO)
/QSPI_SD2: U4.54 (QSPI_SD2), U6.3 (IO2)
/QSPI_SD3: U4.51 (QSPI_SD3), U6.7 (IO3)
/VBUS: C1.2, Q2.2 (S), R1.1, R2.2, R4.1, USBC1.A4 (VBUS), USBC1.A9 (VBUS), USBC1.B4 (VBUS), USBC1.B9 (VBUS)
/XIN: C6.1, R33.1, U4.20 (XIN), U5.1
/XOUT: R12.2, R33.2, U4.21 (XOUT)
/~QSPI_SS: R13.2, R14.2, U4.56 (~QSPI_SS), U6.1 (~CS)
GND: BT1.2, BUZZER1.2, C1.1, C2.2, C3.1, C4.2, C5.2, C6.2, C7.2, C8.2, C9.2, C10.2, C11.2, C12.2, C13.2, C14.2, C15.2, C16.2, C17.1, C18.1, C19.1, C20.2, C21.2, C22.1, C23.2, C24.1, C25.2, C27.2, C28.2, C29.2, C31.2, C32.1, C33.2, C34.2, C35.2, D1.2 (A), Q1.3 (E), Q3.2 (S), R5.1, R9.2, R10.2, R11.2, R21.1, R22.1, R25.1, R26.2, R28.1, R31.2, SW1.1, U1.1 (GND), U1.7 (GND), U1.11 (DF1), U1.12 (GND), U1.25 (GND), U1.30 (GND), U1.36 (GND), U1.49 (EP), U2.2 (CFG2), U2.9 (CFG1), U2.11 (GND), U3.1 (PGND), U3.4 (AGND), U4.19 (TESTEN), U4.57 (GND), U5.2 (GND), U5.4 (GND), U6.4 (GND), U7.5 (GND), U8.4 (ADDR), U8.6 (VSS), U9.6 (VSS), U11.7 (GND), U12.6 (VSS), U13.5, USBC1.17 (EH), USBC1.18 (EH), USBC1.19 (EH), USBC1.20 (EH), USBC1.A1 (GND), USBC1.A12 (GND), USBC1.B1 (GND), USBC1.B12 (GND)
unnamed: BUZZER1.1 (+), R34.1
unnamed: C5.1, R12.1, U5.3
unnamed: C26.1, R25.2
unnamed: C30.1, D1.1 (K), L2.1, U11.8 (PH)
unnamed: D2.2 (A), M1.2 (-), Q3.3 (D)
unnamed: LED1.2 (A), LED2.1 (C)
unnamed: LED2.2 (A), LED3.1 (C)
unnamed: LED4.2 (A), LED5.1 (C)
unnamed: LED5.2 (A), LED6.1 (C)
unnamed: LED7.2 (A), LED8.1 (C)
unnamed: LED8.2 (A), LED9.1 (C)
unnamed: LED10.2 (A), LED11.1 (C)
unnamed: LED11.2 (A), LED12.1 (C)
unnamed: LED13.2 (A), LED14.1 (C)
unnamed: LED14.2 (A), LED15.1 (C)
unnamed: LED16.2 (A), LED17.1 (C)
unnamed: LED17.2 (A), LED18.1 (C)
unnamed: LED19.2 (A), LED20.1 (C)
unnamed: LED20.2 (A), LED21.1 (C)
unnamed: LED22.2 (A), LED23.1 (C)
unnamed: LED23.2 (A), LED24.1 (C)
unnamed: LED25.2 (A), LED26.1 (C)
unnamed: LED26.2 (A), LED27.1 (C)
unnamed: LED28.2 (A), LED29.1 (C)
unnamed: LED29.2 (A), LED30.1 (C)
unnamed: LED31.2 (A), LED32.1 (C)
unnamed: LED32.2 (A), LED33.1 (C)
unnamed: LED34.2 (A), LED35.1 (C)
unnamed: LED35.2 (A), LED36.1 (C)
unnamed: LED37.2 (A), LED38.1 (C)
unnamed: LED38.2 (A), LED39.1 (C)
unnamed: LED40.2 (A), LED41.1 (C)
unnamed: LED41.2 (A), LED42.1 (C)
unnamed: LED43.2 (A), LED44.1 (C)
unnamed: LED44.2 (A), LED45.1 (C)
unnamed: LED46.2 (A), LED47.1 (C)
unnamed: LED47.2 (A), LED48.1 (C)
unnamed: LED49.2 (A), LED50.1 (C)
unnamed: LED50.2 (A), LED51.1 (C)
unnamed: LED52.2 (A), LED53.1 (C)
unnamed: LED53.2 (A), LED54.1 (C)
unnamed: LED55.2 (A), LED56.1 (C)
unnamed: LED56.2 (A), LED57.1 (C)
unnamed: LED58.2 (A), LED59.1 (C)
unnamed: LED59.2 (A), LED60.1 (C)
unnamed: LED61.2 (A), LED62.1 (C)
unnamed: LED62.2 (A), LED63.1 (C)
unnamed: LED64.2 (A), LED65.1 (C)
unnamed: LED65.2 (A), LED66.1 (C)
unnamed: LED67.2 (A), LED68.1 (C)
unnamed: LED68.2 (A), LED69.1 (C)
unnamed: LED70.2 (A), LED71.1 (C)
unnamed: LED71.2 (A), LED72.1 (C)
unnamed: Q1.2 (B), R3.1
unnamed: Q1.1 (C), Q2.1 (G), R4.2
unnamed: Q3.1 (G), R31.1, R32.1
unnamed: R14.1, SW1.4
unnamed: R11.1, U1.26 (REXTB)
unnamed: R10.1, U1.27 (REXTG)
unnamed: R9.1, U1.28 (REXTR)
unnamed: C2.1, R1.2, U2.1 (VDD), U2.3 (CFG3)
unnamed: R2.1, U2.8 (VBUS)
unnamed: R5.2, R6.2, U3.5 (FB)
unnamed: L1.1, U3.7 (SW)
unnamed: GP24.1 (1_1), U4.36 (GPIO24)
unnamed: GP25.1 (1_1), U4.37 (GPIO25)
unnamed: GP26.1 (1_1), U4.38 (GPIO26/ADC0)
unnamed: GP27.1 (1_1), U4.39 (GPIO27/ADC1)
unnamed: R7.2, U4.46 (USB_DM)
unnamed: R8.2, U4.47 (USB_DP)
unnamed: C17.2, C18.2, C19.2, U4.23 (DVDD), U4.45 (VREG_VOUT), U4.50 (DVDD)
unnamed: BT1.1, U7.6 (VBAT)
unnamed: E1.1 (1_1), U8.8 (ELE0)
unnamed: E2.1 (1_1), U8.9 (ELE1)
unnamed: E3.1 (1_1), U8.10 (ELE2)
unnamed: E4.1 (1_1), U8.11 (ELE3)
unnamed: E5.1 (1_1), U8.12 (LED0/ELE4)
unnamed: E6.1 (1_1), U8.13 (LED1/ELE5)
unnamed: E7.1 (1_1), U8.14 (LED2/ELE6)
unnamed: E8.1 (1_1), U8.15 (LED3/ELE7)
unnamed: E9.1 (1_1), U8.16 (LED4/ELE8)
unnamed: E10.1 (1_1), U8.17 (LED5/ELE9)
unnamed: E11.1 (1_1), U8.18 (LED6/ELE10)
unnamed: E12.1 (1_1), U8.19 (LED7/ELE11)
unnamed: R21.2, U8.7 (REXT)
unnamed: C22.2, U8.5 (VREG)
unnamed: E13.1 (1_1), U9.8 (ELE0)
unnamed: E14.1 (1_1), U9.9 (ELE1)
unnamed: E15.1 (1_1), U9.10 (ELE2)
unnamed: E16.1 (1_1), U9.11 (ELE3)
unnamed: E17.1 (1_1), U9.12 (LED0/ELE4)
unnamed: E18.1 (1_1), U9.13 (LED1/ELE5)
unnamed: E19.1 (1_1), U9.14 (LED2/ELE6)
unnamed: E20.1 (1_1), U9.15 (LED3/ELE7)
unnamed: E21.1 (1_1), U9.16 (LED4/ELE8)
unnamed: E22.1 (1_1), U9.17 (LED5/ELE9)
unnamed: E23.1 (1_1), U9.18 (LED6/ELE10)
unnamed: E24.1 (1_1), U9.19 (LED7/ELE11)
unnamed: R22.2, U9.7 (REXT)
unnamed: C24.2, U9.5 (VREG)
unnamed: C30.2, U11.1 (BOOT)
unnamed: C25.1, C26.2, U11.6 (COMP)
unnamed: C27.1, U11.4 (SS)
unnamed: R26.1, R27.2, U11.5 (VSENSE)
unnamed: E25.1 (1_1), U12.8 (ELE0)
unnamed: E26.1 (1_1), U12.9 (ELE1)
unnamed: E27.1 (1_1), U12.10 (ELE2)
unnamed: E28.1 (1_1), U12.11 (ELE3)
unnamed: R28.2, U12.7 (REXT)
unnamed: C32.2, U12.5 (VREG)

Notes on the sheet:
RP2040
RTC
MCU
Capacitive touch
LEDs
USB & POWER
Display connector

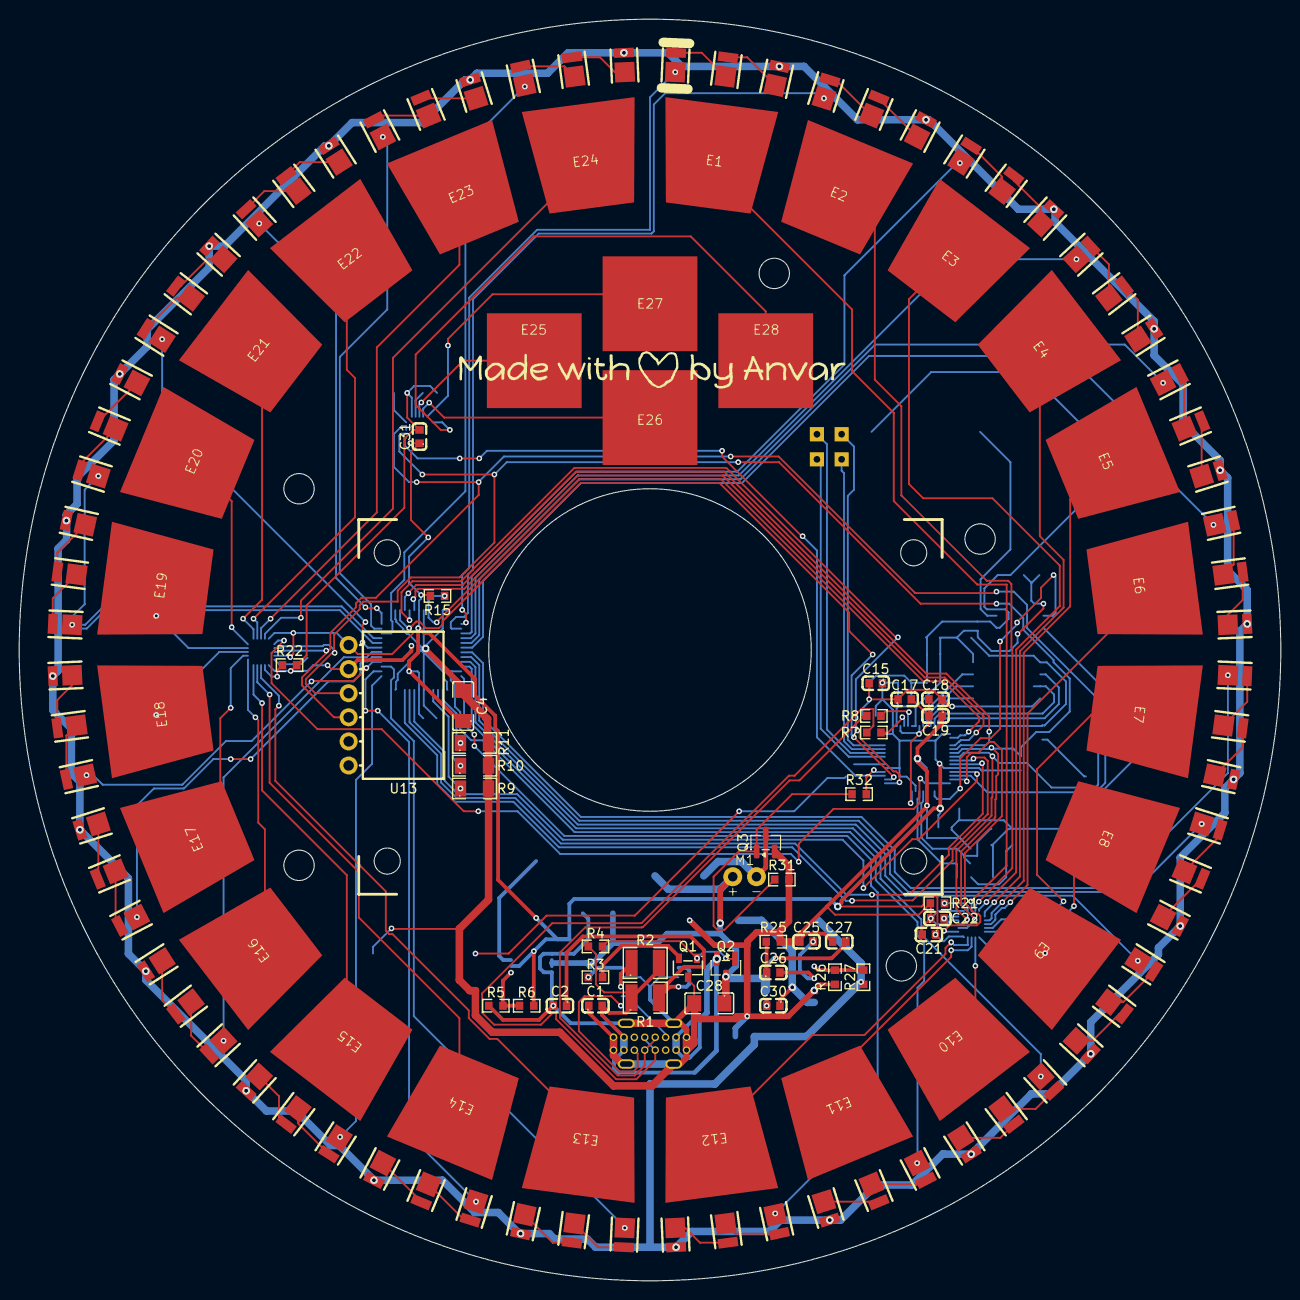
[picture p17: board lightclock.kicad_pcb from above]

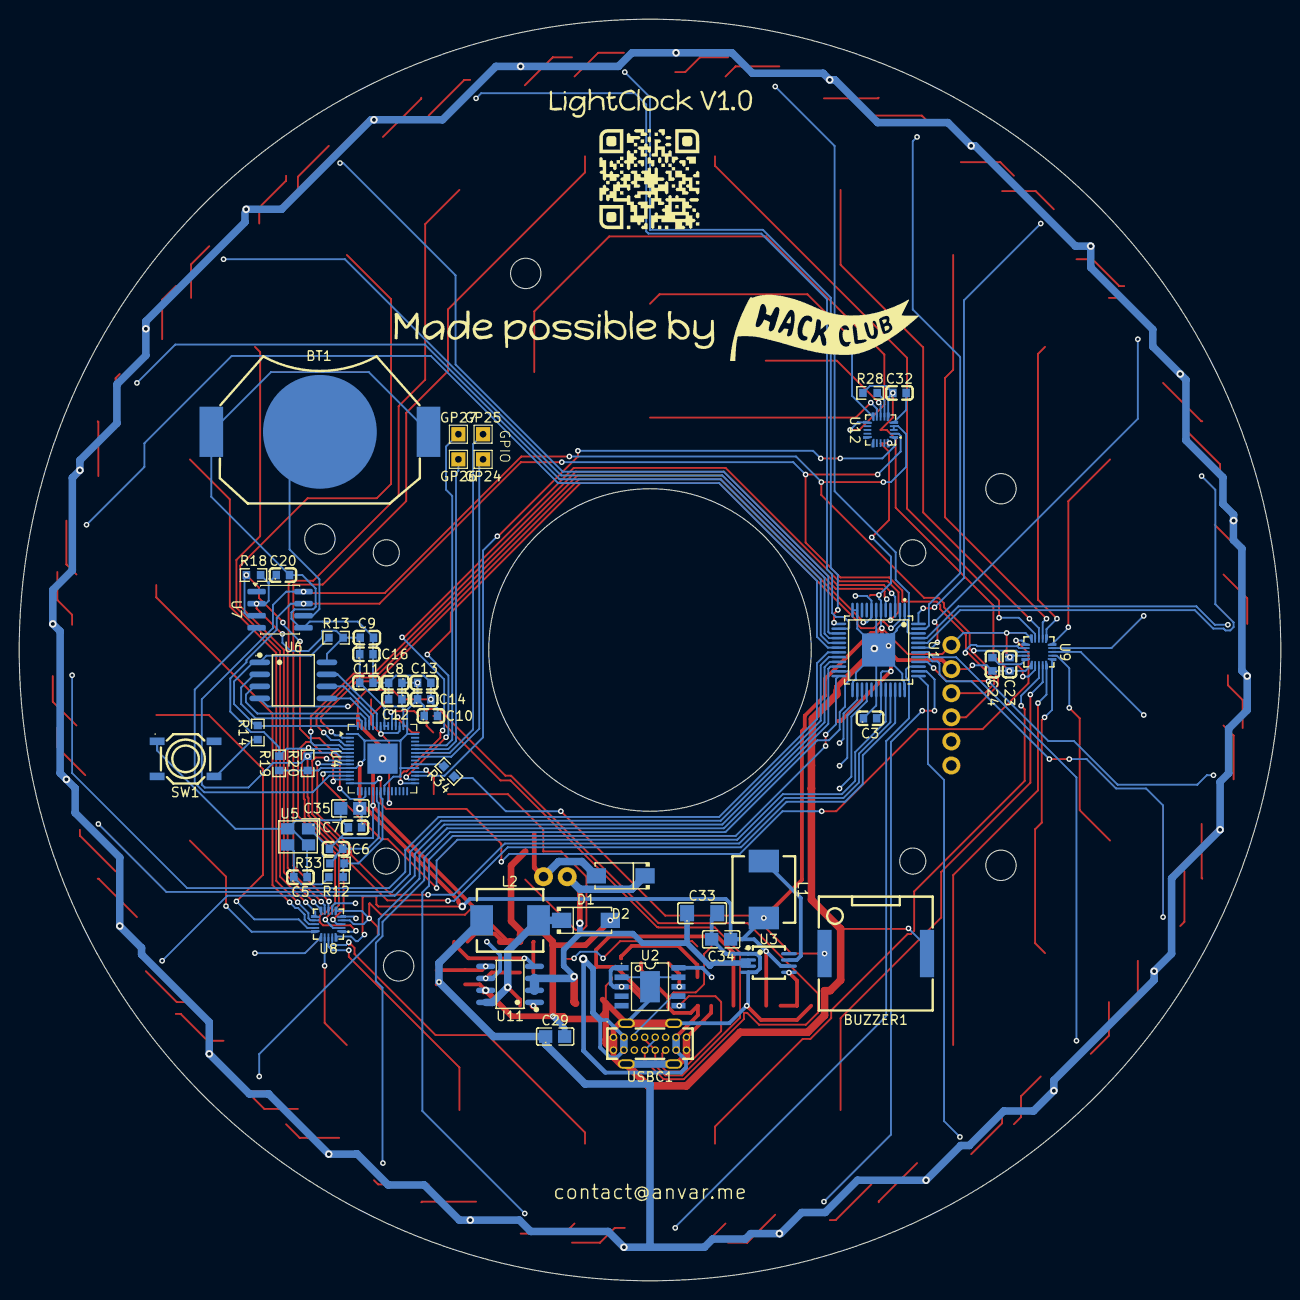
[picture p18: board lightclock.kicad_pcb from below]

Board: 2 copper layers, 133.0 x 133.0 mm, 191 parts (52 on the bottom side), 169 nets.

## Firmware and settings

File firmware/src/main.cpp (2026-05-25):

#include <Arduino.h>
#include <Wire.h>
#include <U8g2lib.h>
#include <MUIU8g2.h>
#include <Adafruit_MPR121.h>
#include <DS3231.h>
#include <SPI.h>
#include <Ticker.h>

#ifndef _BV
#define _BV(bit) (1 << (bit)) 
#endif

#define CONTROLS_COOLDOWN 150 // ms

#define OE0   6
#define OE1   7
#define OE2   8
#define LE_DM 3
#define DM    2
#define TF    0

#define PWM_STEPS 256
#define PWM_FREQ  200
#define PWM_PERIOD_US (1000000 / (PWM_STEPS * PWM_FREQ))

#define BUZZER 22

#define I2C0_SDA 4
#define I2C0_SCL 5

#define MPR121_0_IRQ 10
#define MPR121_1_IRQ 11
#define MPR121_2_IRQ 20

#define MPR121_AUTOCONFIG true


// display

U8G2_SSD1309_128X64_NONAME0_F_HW_I2C display(
  U8G2_R2, // 180 degrees rotation because the screen is flipped
  U8X8_PIN_NONE,
  I2C0_SCL,
  I2C0_SDA
);


// RTC

DS3231 RTC;
bool h12;
bool hPM;

bool rtcInterruptFired = true;

// capacitive touch buttons

Adafruit_MPR121 mpr121_0 = Adafruit_MPR121();
Adafruit_MPR121 mpr121_1 = Adafruit_MPR121();
Adafruit_MPR121 mpr121_2 = Adafruit_MPR121();

volatile bool irqFired = false;

bool circleClicked = false;
uint8_t circleClickedId = 0;

enum ControlButton {
  CB_SQUARE, CB_DOWN, CB_UP, CB_SELECT
};
bool controlsClicked = false;
bool controlsJustClicked = false;
ControlButton controlButtonClicked = CB_SQUARE;
uint64_t lastControlsClickTime = 0;
uint64_t lastButtonActivity = 0;


// LEDs

uint8_t leds[24] = {0};
volatile uint8_t pwmCounter = 0;


// state management & UX

uint64_t lastTimeUpdateTime = 0; // the time of the last update of the time when the device is inactive

enum State {
  INACTIVE, HOME, ALARM_H, ALARM_M
};
State currentState = HOME;
uint8_t selector = 0;


// alarm

uint8_t hours = 0;
uint8_t minutes = 0;
bool alarmOn = false;

// config

uint64_t timeInactive = 60 * 1000; // how much time after last button press to set state to inactive (in ms)

void onIRQ() {
  irqFired = true;
}

void setup() {
  Wire.begin();

  // display
  display.begin();
  display.clearBuffer();

  // capacitive touch ICs
  mpr121_0.begin(0x5A, &Wire, MPR121_TOUCH_THRESHOLD_DEFAULT, MPR121_RELEASE_THRESHOLD_DEFAULT, MPR121_AUTOCONFIG);
  mpr121_1.begin(0x5B, &Wire, MPR121_TOUCH_THRESHOLD_DEFAULT, MPR121_RELEASE_THRESHOLD_DEFAULT, MPR121_AUTOCONFIG);
  mpr121_2.begin(0x5C, &Wire, MPR121_TOUCH_THRESHOLD_DEFAULT, MPR121_RELEASE_THRESHOLD_DEFAULT, MPR121_AUTOCONFIG);

  pinMode(MPR121_0_IRQ, INPUT_PULLUP);
  pinMode(MPR121_1_IRQ, INPUT_PULLUP);
  pinMode(MPR121_2_IRQ, INPUT_PULLUP);

  attachInterrupt(digitalPinToInterrupt(MPR121_0_IRQ), onIRQ, FALLING);
  attachInterrupt(digitalPinToInterrupt(MPR121_1_IRQ), onIRQ, FALLING);
  attachInterrupt(digitalPinToInterrupt(MPR121_2_IRQ), onIRQ, FALLING);

  // RTC

  RTC.setClockMode(false);

  if (!RTC.oscillatorCheck()) {
    RTC.setEpoch(1779637745); // !!! modify this to your current time
  }

  RTC.setA1Time(
    0, 0, 0, 0, 0b1111, false, false, false
  );
  RTC.turnOnAlarm(1);
  RTC.checkIfAlarm(1);

  // LED driver

  pinMode(OE0, OUTPUT);
  pinMode(OE1, OUTPUT);
  pinMode(OE2, OUTPUT);
  pinMode(LE_DM, OUTPUT);
  pinMode(DM, OUTPUT);
  pinMode(TF, INPUT);

  digitalWrite(OE0, LOW);
  digitalWrite(OE1, LOW);
  digitalWrite(OE2, LOW);
  digitalWrite(LE_DM, LOW);
  digitalWrite(DM, LOW);

  SPI.begin();
  SPI.beginTransaction(SPISettings(8000000, MSBFIRST, SPI_MODE0));
}

void setup1() {}

void updatePWM() {
  uint32_t state = 0;
  for (uint8_t channel = 0; channel < 24; channel++) {
    if (leds[channel] > pwmCounter) {
      state |= (1UL << (23 - channel));
    }
  }

  SPI.transfer((state >> 16) & 0xFF);
  SPI.transfer((state >> 8) & 0xFF);
  SPI.transfer(state & 0xFF);

  digitalWrite(LE_DM, HIGH);
  digitalWrite(LE_DM, LOW);

  pwmCounter++;
}

void playTone(int pin, int frequency, int duration) {
  int period = 1000000 / frequency;
  int halfPeriod = period / 2;
  long cycles = (long)frequency * duration / 1000;

  for (long i = 0; i < cycles; i++) {
    digitalWrite(pin, HIGH);
    delayMicroseconds(halfPeriod);
    digitalWrite(pin, LOW);
    delayMicroseconds(halfPeriod);
  }
}


void updateMPR121s() {
  if (!irqFired) return;
  irqFired = false;

  int16_t maxDelta = 0;
  int8_t maxDeltaId = -1;

  for (uint8_t i = 0; i < 24; i++) {
    int16_t delta = 0;

    if (i < 12) {
      delta = mpr121_0.filteredData(i) - mpr121_0.baselineData(i);
    } else {
      delta = mpr121_1.filteredData(i-12) - mpr121_1.baselineData(i-12);
    }

    if (delta >= MPR121_TOUCH_THRESHOLD_DEFAULT) {
      if (maxDelta < delta) {
        maxDelta = delta;
        maxDeltaId = i;
      }
    }
  }

  if (maxDeltaId != -1) {
    circleClicked = true;
    circleClickedId = maxDeltaId;
    lastButtonActivity = millis();

    if (currentState == INACTIVE) {
      currentState = HOME;
    }
  } else {
    circleClicked = false;
  }

  maxDelta = 0;
  maxDeltaId = -1;

  for (uint8_t i = 0; i < 4; i++) {
    int16_t delta = mpr121_0.filteredData(i) - mpr121_0.baselineData(i);

    if (delta >= MPR121_TOUCH_THRESHOLD_DEFAULT) {
      if (maxDelta < delta) {
        maxDelta = delta;
        maxDeltaId = i;
      }
    }
  }

  if (maxDeltaId != -1) {
    if (controlsClicked == false) {
      controlsJustClicked = true;
    }
    controlsClicked = true;
    controlButtonClicked = (ControlButton) maxDeltaId;
    if (currentState == INACTIVE) {
      currentState = HOME;
    }
  }
}

void updateTimeOnDisplay() {
  if (currentState != INACTIVE) {return;}

  display.clearBuffer();
  display.setFont(u8g2_font_logisoso38_tn);
  display.drawStr(20, 10, RTC.getHour(h12, hPM) + ":" + RTC.getMinute());
  display.sendBuffer();
}

void handleControlClicks() {
  if (!controlsJustClicked || millis() - lastControlsClickTime < CONTROLS_COOLDOWN) {return;}
  controlsJustClicked = false;
  lastControlsClickTime = millis();

  switch (controlButtonClicked)
  {
  case CB_SELECT:
    switch (currentState)
    {
    case HOME:
      if (selector == 0) {
        currentState = ALARM_H;
      }
      break;
    
    case ALARM_H:
      hours = circleClickedId;
      currentState = ALARM_M;
      break;

    case ALARM_M:
      minutes = circleClickedId;
      alarmOn = true;
      currentState = HOME;
      break;
    
    default:
      break;
    }
    break;

  case CB_SQUARE:
    currentState = HOME;
    break;
  
  default:
    break;
  }
}

void handleAlarm() {
  if (alarmOn) {return;}

  if (millis() - lastButtonActivity < 2000) {
    alarmOn = false;
    return;
  }

  int64_t curTime = RTClib::now().unixtime();
  int64_t alarmTime = curTime - curTime % 86400 + minutes * 60 + hours * 3600;

  if (alarmTime - curTime < 1200) {
    uint16_t brightness = (1400 - (alarmTime - curTime)) / 5;
    if (brightness > 255) {
      brightness = 255;
    }

    memset(leds, brightness, sizeof(leds));
  }

  if (curTime - alarmTime >= 0) {
    playTone(BUZZER, 1000, 500);
  }
}

void onSecond() {
  if (millis() - lastButtonActivity > timeInactive) {
    currentState = INACTIVE;
  }

  updateTimeOnDisplay();
  handleAlarm();
}

void onRTCAlarmInterrup() {
  rtcInterruptFired = true;
}

void loop1() {
  updatePWM();
  delayMicroseconds(PWM_PERIOD_US);
}

void loop() {
  updateMPR121s();
  handleControlClicks();
  updateTimeOnDisplay();

  if (rtcInterruptFired) {
    rtcInterruptFired = false;
    RTC.checkIfAlarm(1);
    onSecond();
  }
}

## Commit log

2026-05-17 organised BOM
    [BOM.csv, lightclock_bom.csv, lightclock_positions.csv]
2026-05-19 added spare GPIO pads & ventilation for enclosure back
    [Back.f3d, Back.step, enclosure-back.f3d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]
2026-05-21 added more CAD files & images
    [enclosure-back-fusion.f3d, enclosure-back.f3d, enclosure-back.stl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]
2026-05-21 updated BOM & images
    [BOM.csv, lightclock_bom.csv, lightclock_positions.csv]
2026-05-22 modified coupled images to be in a row
2026-05-24 added state management & control buttons handling
2026-05-24 connected INT pin on RTC to RP2040 for alarms
    [lightclock.kicad_pcb, lightclock.kicad_sch]
2026-05-25 updated PCB & schematic images
2026-05-25 updated BOM & added totals to README
    [BOM.csv]
2026-05-25 update production folder for PCB
    [lightclock_bom.csv, lightclock_designators.csv, lightclock_positions.csv]
2026-05-30 updated BOM
    [BOM.csv]
2026-08-08 added a smaller png version of assembly sideview image
